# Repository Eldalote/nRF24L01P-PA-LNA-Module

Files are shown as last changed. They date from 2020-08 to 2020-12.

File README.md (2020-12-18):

# nRF24L01P-PA-LNA-Module DO NOT USE

DO NOT USE THIS DESIGN!
When doing further projects with the nRF24L01p and PA LNA module, I came to the conclusion that I made some significant design errors in this design.
The current version of the design might function, maybe, but I know for sure that there are some errors.
For a better design look at my Drone project. Both the drone PCB and the remote PCB have this module integrated on the PCB.

PCB Design for nRF24L01P PA LNA module

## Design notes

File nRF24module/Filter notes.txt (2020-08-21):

Note on LC filter choices:

Original in datasheet is 1.5pF and 2.4nH This results in a 2.65GHz cutoff frequency.
However, I was not able to source (for reasonable prices) components with those specific values.
I chose 1.0pF and 2.7nH instead. Tollerances are 0.25 pF and 0.3 nH. extreme case scenarios are 0.75 pF and 2.4 nH resulting in a cutoff of 3.75 GHz, and 1.25 pF and 3 nH resulting in a cutoff of 2.6GHz. 
Not ideal, but I would rather overshoot the cutoff frequency than accidentally cut off the used frequency.

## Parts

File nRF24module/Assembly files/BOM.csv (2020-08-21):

Comment | Designator | Footprint | LCSC Part #
0.3pF | C11 | 0603_C | C170140
1pF | C12,C13,C14,C15,C6 | 0402_C | C1550
220pF | C16 | 0402_C | C1530
1uF | C18 | 0402_C | C52923
22pF | C1,C2 | 0402_C | C1555
2.2nF | C3 | 0402_C | C1531
4.7pF | C4 | 0402_C | C1569
1.5pF | C5 | 0402_C | C1552
33nF | C7 | 0402_C | C1585
1nF | C8 | 0402_C | C1523
10nF | C9,C17 | 0402_C | C15195
8.2nH | L1 | 0402_L | C16208
2.7nH | L2,L4,L5 | 0402_L | C27123
3.9nH | L3 | 0402_L | C14033
22K | R2 | 0402_R | C25768
1K | R3,R4,R5 | 0402_R | C11702
nRF24L01P | U1 | QFN-20_EP_4.0x4.0x0.5P | C8791
RFX2401C | U2 | QFN-16_EP_3.0x3.0x0.5P | C19213
16MHz | X1 | SMD-3225_4P | C13738

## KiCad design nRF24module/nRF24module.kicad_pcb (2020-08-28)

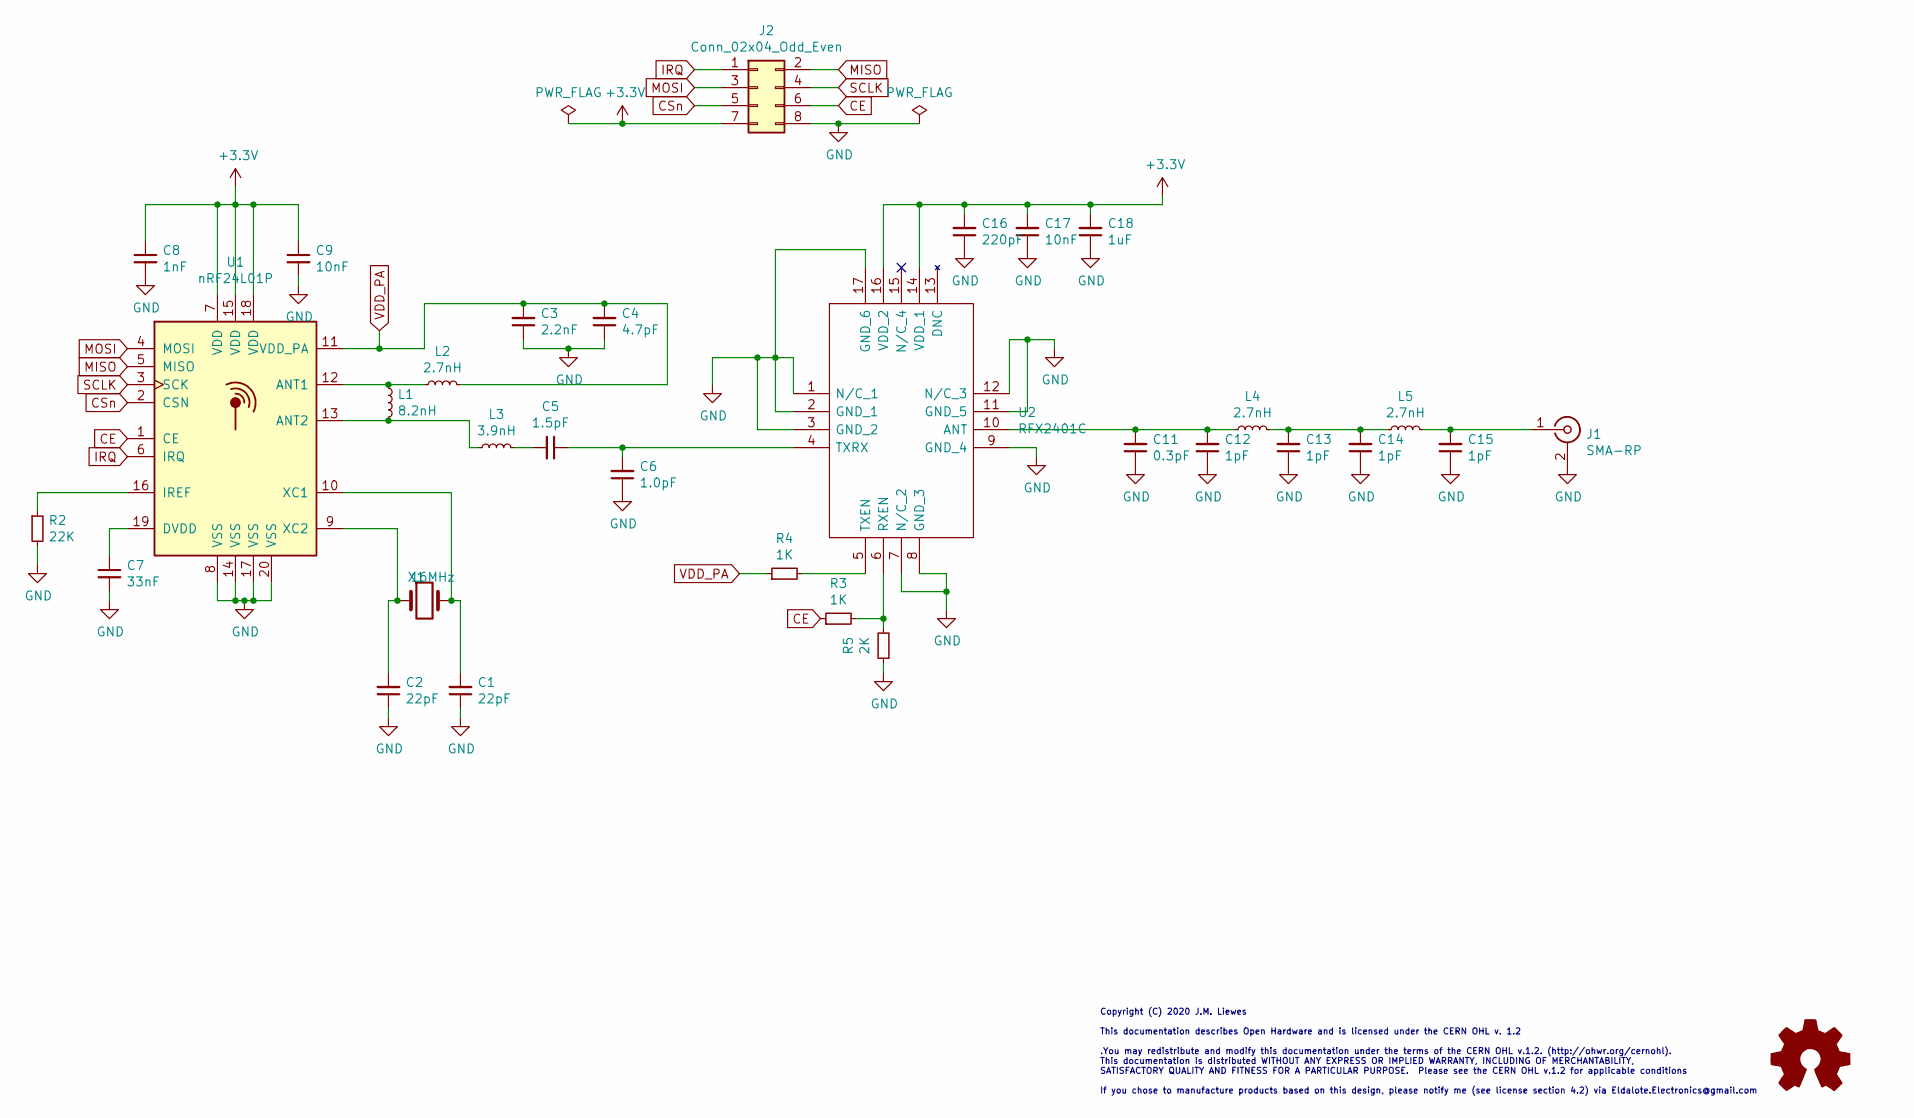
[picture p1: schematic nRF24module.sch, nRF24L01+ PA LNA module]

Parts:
C1, C2: 22pF; C_0402_1005Metric; LCSC C1555
C3: 2.2nF; C_0402_1005Metric; LCSC C1531
C4: 4.7pF; C_0402_1005Metric; LCSC C1569
C5: 1.5pF; C_0402_1005Metric; LCSC C1552
C6: 1.0pF; C_0402_1005Metric; LCSC C1550
C7: 33nF; C_0402_1005Metric; LCSC C1585
C8: 1nF; C_0402_1005Metric; LCSC C1523
C9, C17: 10nF; C_0402_1005Metric; LCSC C15195
C11: 0.3pF; C_0603_1608Metric; LCSC C170140
C12, C13, C14, C15: 1pF; C_0402_1005Metric; LCSC C1550
C16: 220pF; C_0402_1005Metric; LCSC C1530
C18: 1uF; C_0402_1005Metric; LCSC C52923
J1: SMA-RP; SMA_Samtec_SMA-J-P-X-ST-EM1_EdgeMount
J2: Conn_02x04_Odd_Even; PinHeader_2x04_P1.27mm_Vertical
L1: 8.2nH; L_0402_1005Metric; LCSC C16208
L2, L4, L5: 2.7nH; L_0402_1005Metric; LCSC C27123
L3: 3.9nH; L_0402_1005Metric; LCSC C14033
LOGO1: Logo_Open_Hardware_Small; OSHW-Logo2_7.3x6mm_SilkScreen
R2: 22K; R_0402_1005Metric; LCSC C25768
R3, R4: 1K; R_0402_1005Metric; LCSC C11702
R5: 2K; R_0402_1005Metric; LCSC C4109
U1: nRF24L01P; QFN-20-1EP_4x4mm_P0.5mm_EP2.5x2.5mm; LCSC C8791
U2: RFX2401C; QFN50P300X300X60-17N-D; Mouser Part Number 477-RFX2401C
X1: 16MHz; Crystal_SMD_3225-4Pin_3.2x2.5mm; LCSC C13738

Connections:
+3V3: C8.1, C9.1, C16.2, C17.2, C18.2, J2.7, U1.7 (VDD), U1.15 (VDD), U1.18 (VDD), U2.14 (VDD_1), U2.16 (VDD_2)
CE: J2.6, R3.1, U1.1 (CE)
CSn: J2.5, U1.2 (CSN)
IRQ: J2.1, U1.6 (IRQ)
MISO: J2.2, U1.5 (MISO)
MOSI: J2.3, U1.4 (MOSI)
unnamed: C2.2, U1.9 (XC2), X1.1
unnamed: C5.1, C6.2, U2.4 (TXRX)
unnamed: C5.2, L3.2
unnamed: C7.1, U1.19 (DVDD)
unnamed: C11.2, C12.2, L4.1, U2.10 (ANT)
unnamed: C13.2, C14.2, L4.2, L5.1
unnamed: C15.2, J1.1 (In), L5.2
unnamed: L1.1, L2.1, U1.12 (ANT1)
unnamed: L1.2, L3.1, U1.13 (ANT2)
unnamed: R2.1, U1.16 (IREF)
unnamed: R3.2, R5.2, U2.6 (RXEN)
unnamed: R4.2, U2.5 (TXEN)
SCLK: J2.4, U1.3 (SCK)
VDD_PA: C3.2, C4.2, L2.2, R4.1, U1.11 (VDD_PA)

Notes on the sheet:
Copyright (C) 2020 J.M. Liewes This documentation describes Open Hardware and is licensed under the CERN OHL v. 1.2 .You may redistribute and modify this documentation under the terms of the CERN OHL v.1.2. (http://ohwr.org/cernohl). This documentation is distributed WITHOUT ANY EXPRESS OR IMPLIED 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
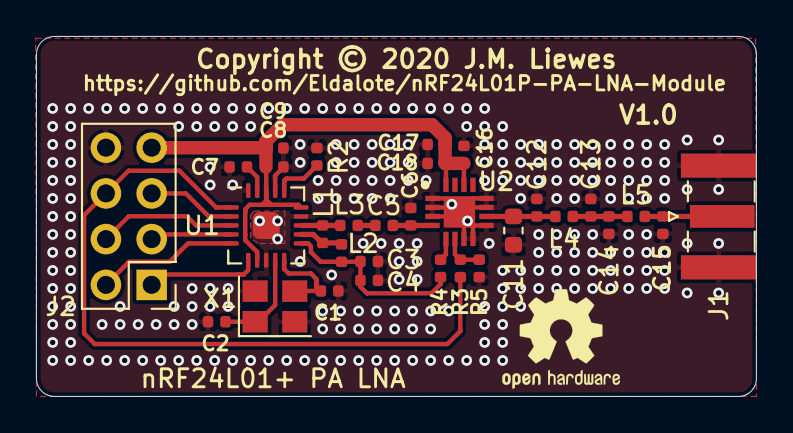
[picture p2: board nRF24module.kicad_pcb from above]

Board: 2 copper layers, 40.0 x 20.0 mm, 32 parts (0 on the bottom side), 22 nets.

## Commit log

2020-08-21 Initial Commit with project
    [nRF24module-B_Cu.gbr, nRF24module-B_Mask.gbr, nRF24module-B_Paste.gbr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]
2020-08-21 Now with production files
    [nRF24module.csv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]
2020-08-23 Update, with Licence added to files, and rerouted PCB, cleaned up some things. Tightened up components, placed traces neater, placed vias neater. Added OSHW logo. TODO: Make own logo and add that.
    [BOM.csv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]
2020-08-28 Added licences, fixed crystal mistake
    [nRF24module.kicad_pcb]
2020-09-16 Corrected crystal load capacitance.
    [nRF24module.sch]
2020-12-18 DO NOT USE DESIGN IN CURRENT STATE

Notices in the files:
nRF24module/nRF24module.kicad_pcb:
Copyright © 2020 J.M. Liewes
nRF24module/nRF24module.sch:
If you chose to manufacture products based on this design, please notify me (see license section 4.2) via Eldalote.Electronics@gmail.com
